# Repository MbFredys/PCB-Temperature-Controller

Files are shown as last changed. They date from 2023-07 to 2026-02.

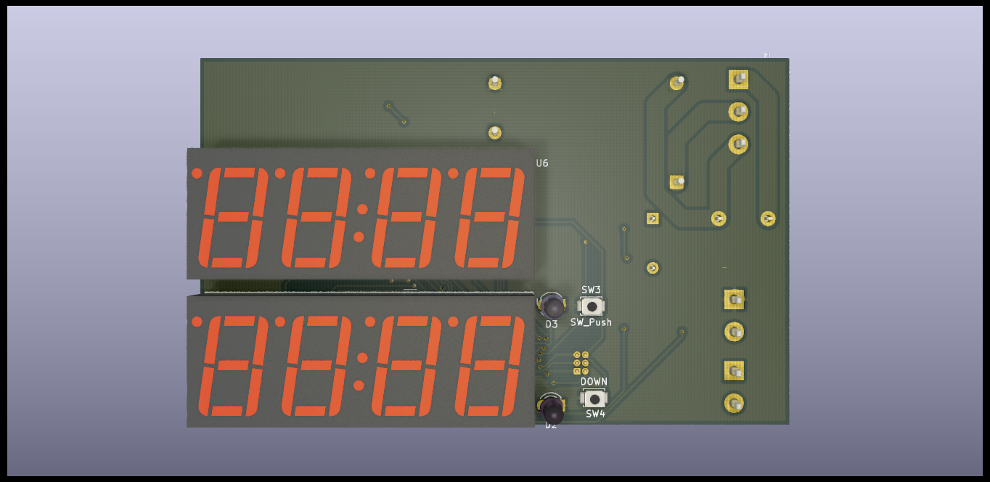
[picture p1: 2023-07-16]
Release/Controlador-temperatura-4.png

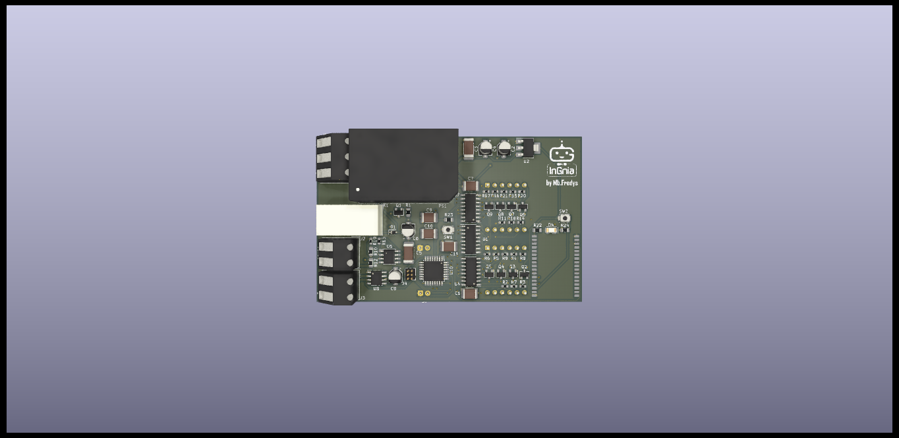
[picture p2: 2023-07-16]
Release/Controlador-temperatura-1.png

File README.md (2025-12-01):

<h1>Temperature Controller</h1>


This is a temperature controller PCB design that allows for precise temperature control with the following features:

1. 🌡️ Displays the current temperature value.
2. 🎯 Displays the desired temperature value.
3. ⬆️⬇️ Two buttons to raise and lower the temperature.
4. 🔌 Accepts a supply voltage of 100-240V AC.
5. 📶 Bluetooth communication.
6. 🌡️ Allows for the use of thermocouple and PT100 type sensors.

<h1>Usage</h1>

To use the temperature controller, follow these steps:

1. Connect the temperature controller to a power source using a 100-240V AC power supply.
2. Connect the desired temperature sensor to the temperature controller.
3. Set the desired temperature using the up and down buttons.
4. Monitor the current temperature on the display.

<h1>Getting Started</h1>

To get started with the temperature controller PCB design, follow these steps:

1. Clone this repository to your local machine.
2. Open the PCB design files in your preferred KiCAD software.
3. Review the design and make any necessary modifications.
4. Export the design files to your preferred format.
5. Send the design files to a PCB manufacturer for production.

<h1>Contributing</h1>

If you would like to contribute to the LED controller PCB design, please follow these steps:

1. Fork this repository.
2. Create a new branch.
3. Make your changes and commit them.
4. Submit a pull request.

<h1>License</h1>
This project is licensed under the CERN Open Hardware Licence Version 2 - Weakly Reciprocal (CERN-OHL-W-2.0).
See the <a href="https://gitlab.com/ohwr/project/cernohl/-/wikis/uploads/82b567f43ce515395f7ddbfbad7a8806/cern_ohl_w_v2.txt" target="_blank">CERN-OHL-W-2.0 ↗</a> file for more information.</p>

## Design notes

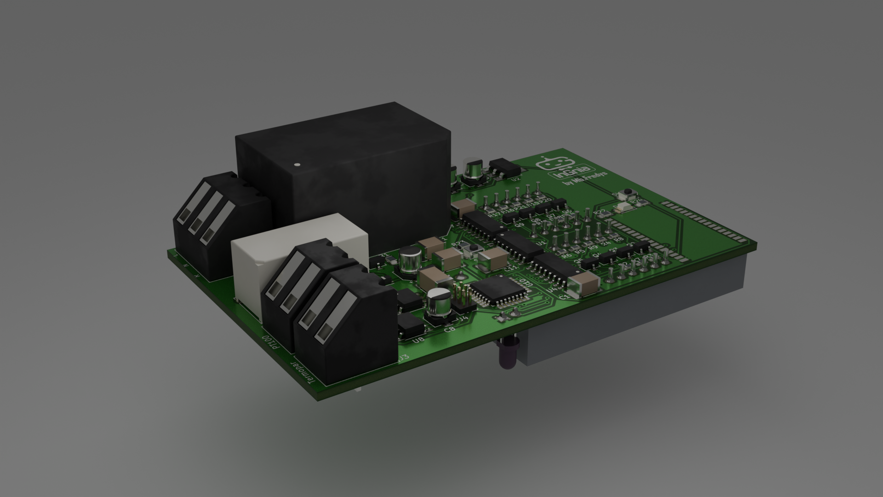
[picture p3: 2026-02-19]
Release/Controlador-temperatura-pro 1.png

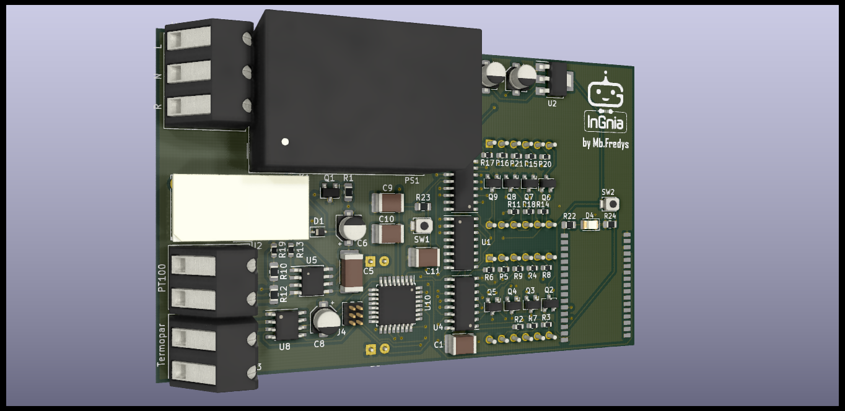
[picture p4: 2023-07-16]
Release/Controlador-temperatura-5.png

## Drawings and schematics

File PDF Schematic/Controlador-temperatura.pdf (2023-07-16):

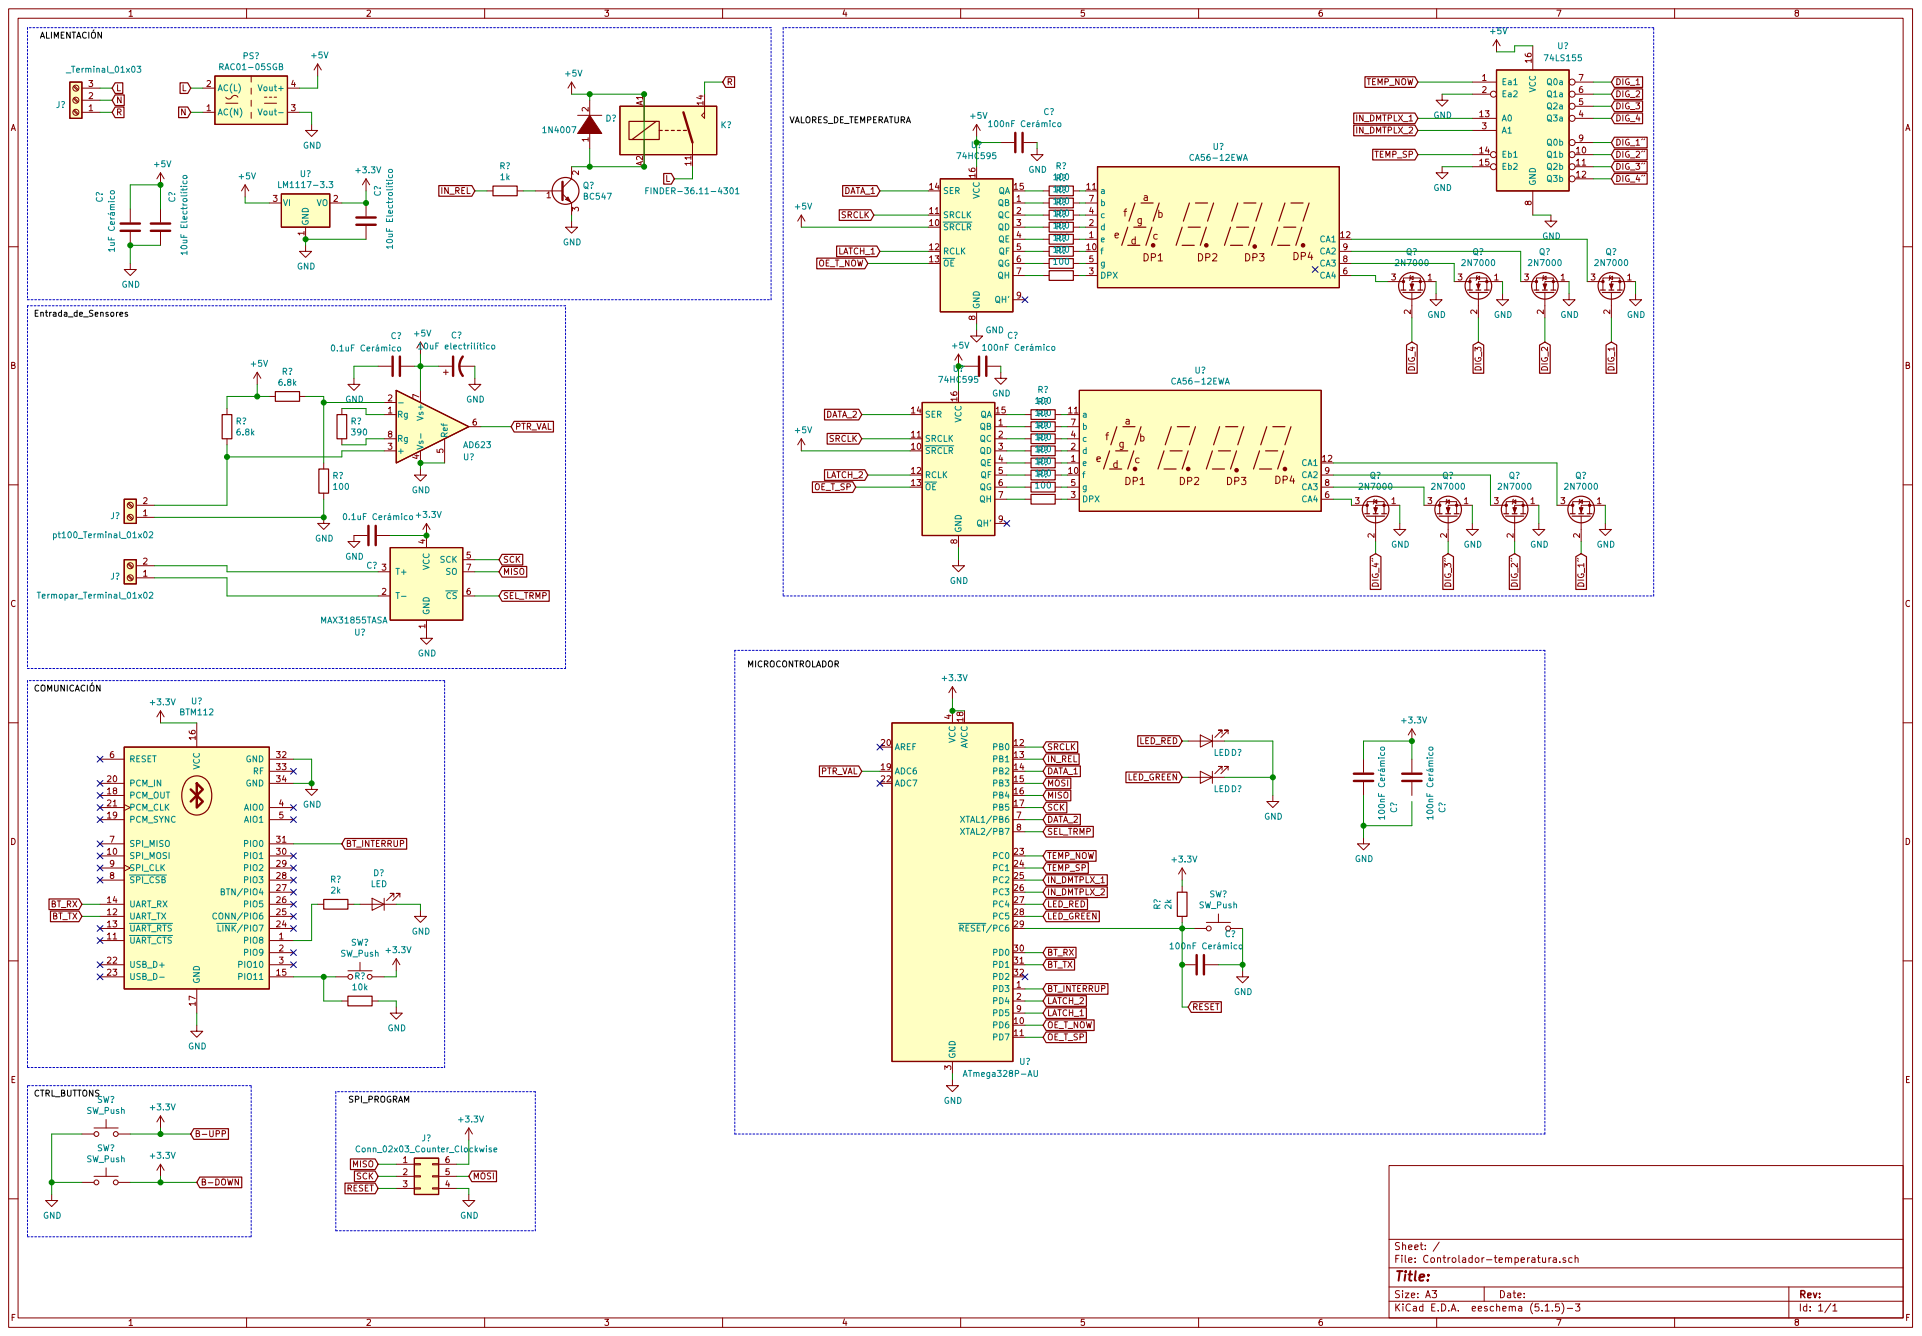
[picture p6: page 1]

SPI_PROGRAM +3.3V J? Conn_02x03_Counter_Clockwise

GND

File: Controlador-temperatura.sch Sheet: /

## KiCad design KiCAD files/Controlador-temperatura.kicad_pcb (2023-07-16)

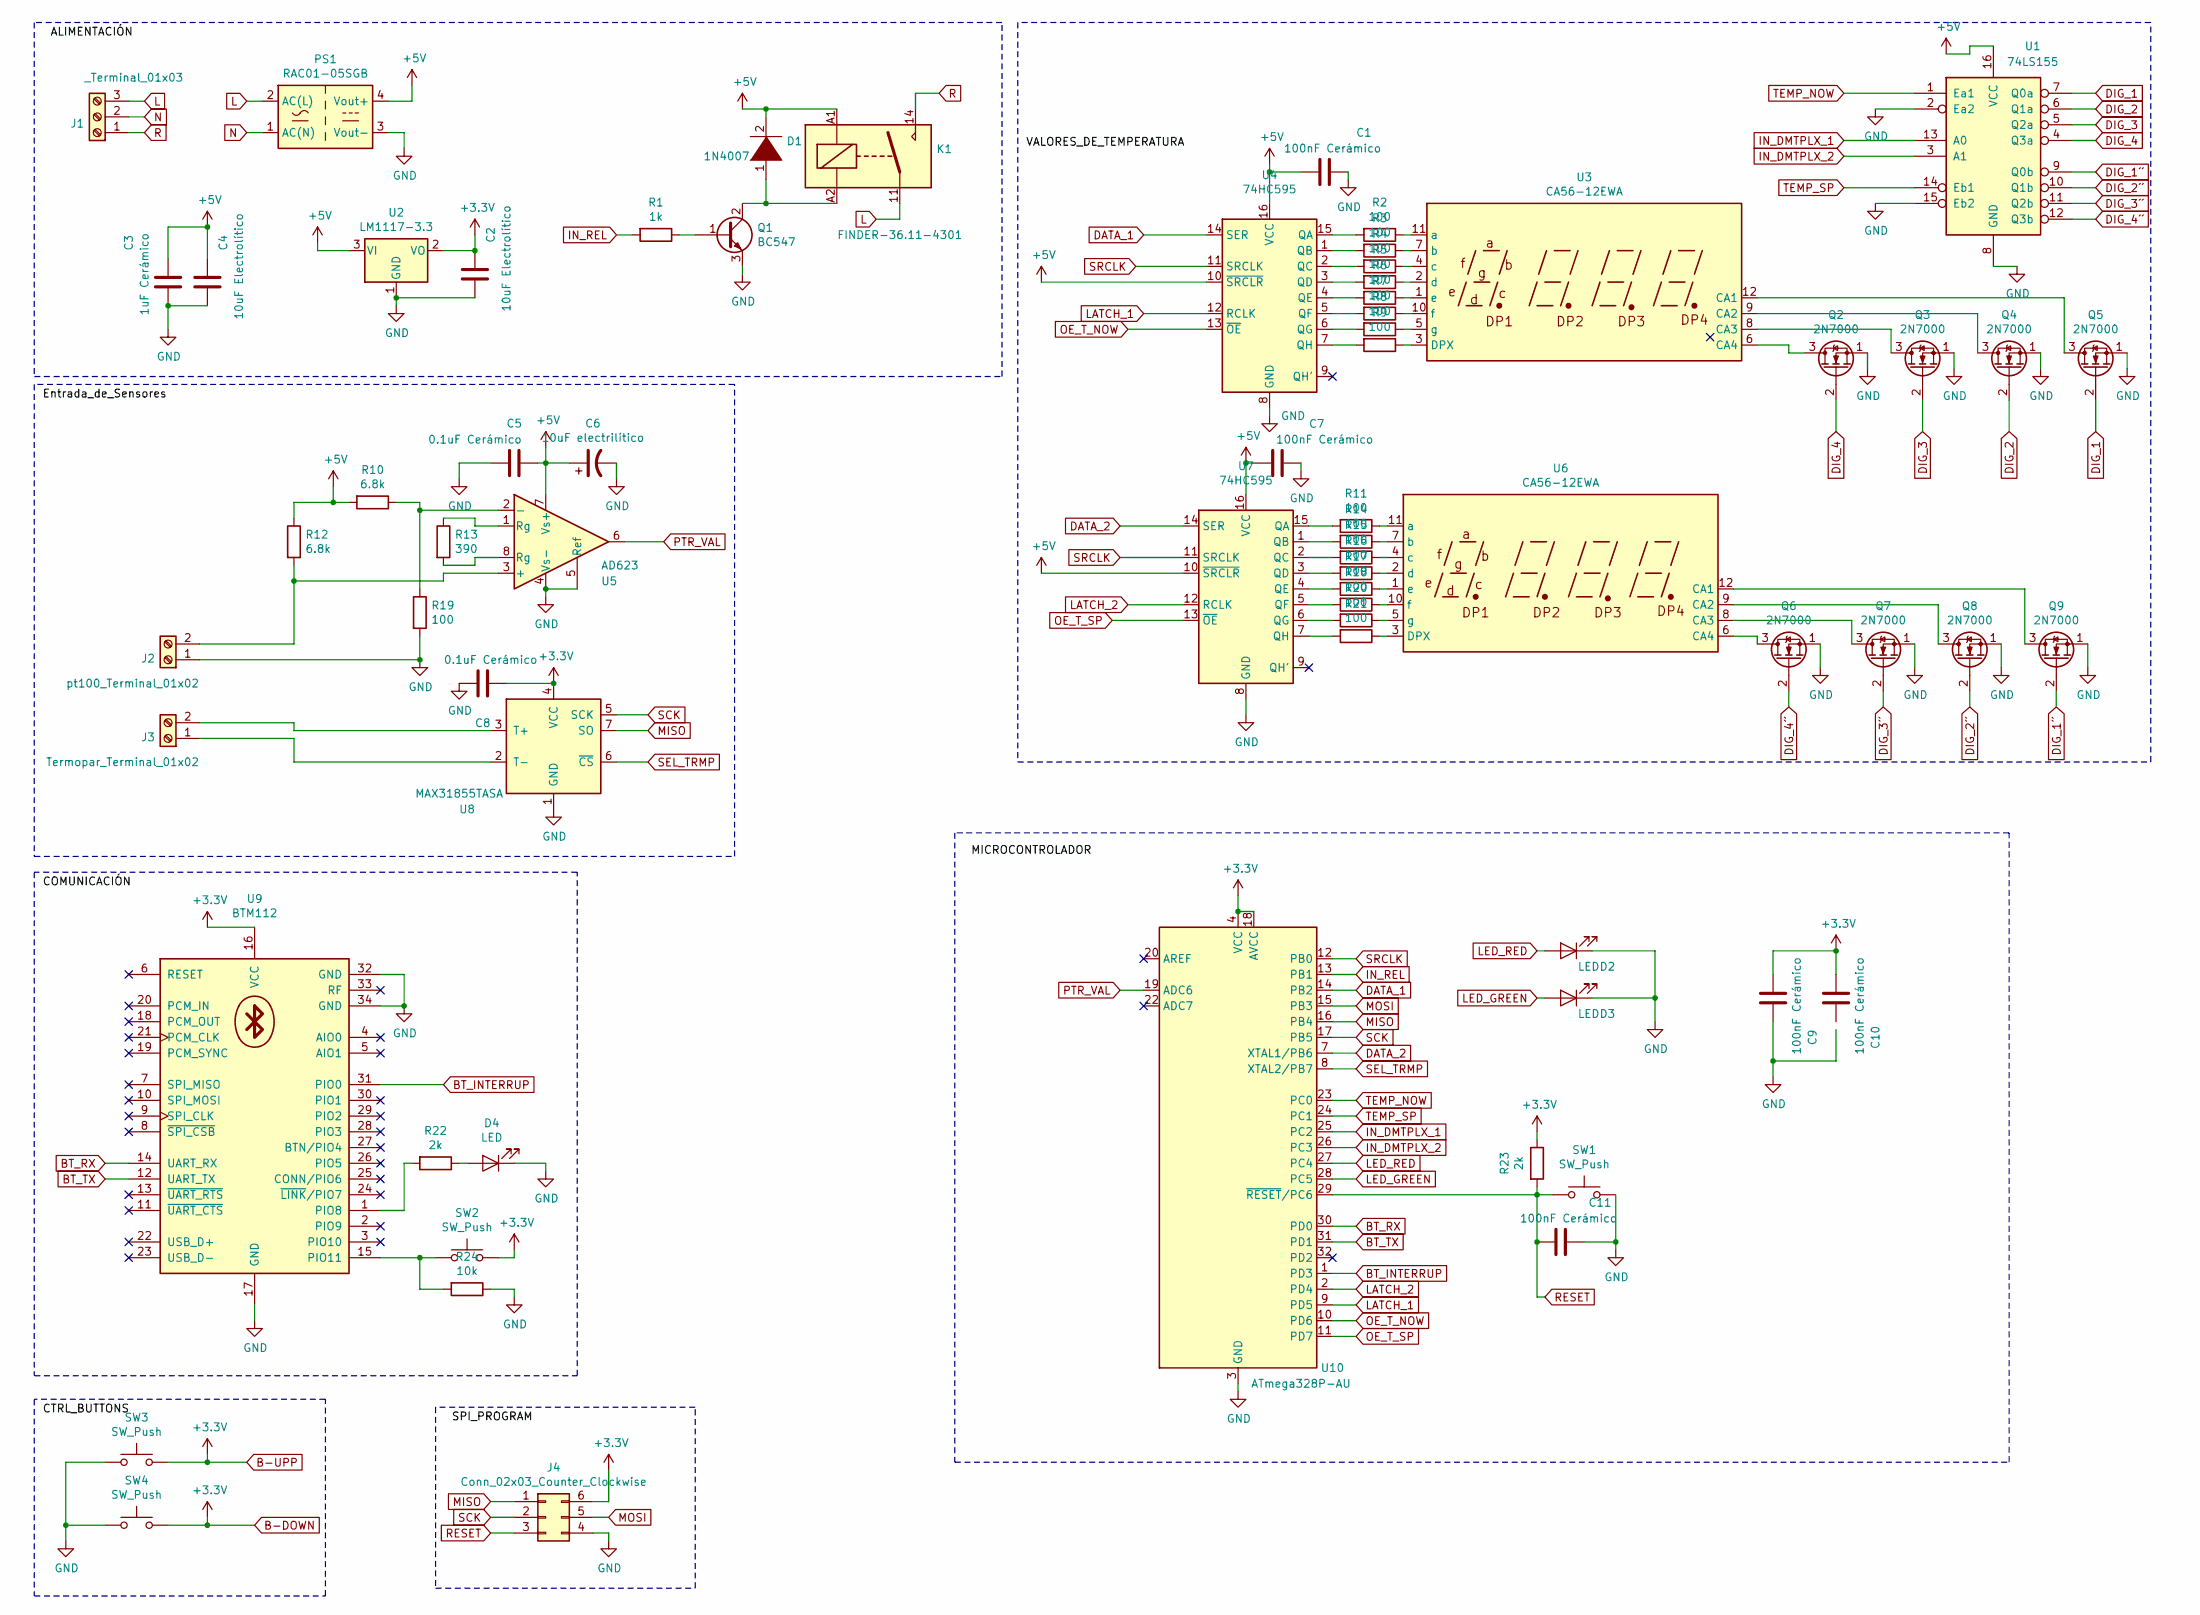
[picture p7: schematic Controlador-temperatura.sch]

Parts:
C1, C7, C9, C10, C11: 100nF Cerámico; C_1812_4532Metric_Pad1.30x3.40mm_HandSolder
C2, C4: 10uF Electrolítico; CP_Elec_4x4.5
C3: 1uF Cerámico; C_2512_6332Metric_Pad1.52x3.35mm_HandSolder
C5: 0.1uF Cerámico; C_2512_6332Metric_Pad1.52x3.35mm_HandSolder
C6: 10uF electrilítico; CP_Elec_4x4.5
C8: 0.1uF Cerámico; CP_Elec_4x4.5
D1: 1N4007; D_SOD-323
D2: LED; LED_D3.0mm_IRBlack
D3: LED; LED_D3.0mm_IRGrey
D4: LED; LED_1206_3216Metric
J1: _Terminal_01x03; TerminalBlock_Altech_AK300-3_P5.00mm
J2: pt100_Terminal_01x02; Altech_AK300_1x02_P5.00mm_45-Degree
J3: Termopar_Terminal_01x02; Altech_AK300_1x02_P5.00mm_45-Degree
J4: Conn_02x03_Counter_Clockwise; PinHeader_2x03_P1.27mm_Vertical
K1: FINDER-36.11-4301; Relay_SPST_Finder_32.21-x300
PS1: RAC01-05SGB; Converter_ACDC_RECOM_RAC01-xxSGB_THT
Q1: BC547; SC-59
Q2, Q3, Q4, Q5, Q6, Q7, Q8, Q9: 2N7000; SC-59
R1: 1k; R_0805_2012Metric_Pad1.15x1.40mm_HandSolder
R2, R3, R4, R5, R6, R7, R8, R9, R11, R14, R15, R16, R17, R18, R19, R20, R21: 100; R_0603_1608Metric
R10, R12: 6.8k; R_0805_2012Metric_Pad1.15x1.40mm_HandSolder
R13: 390; R_0603_1608Metric
R22, R23: 2k; R_0805_2012Metric_Pad1.15x1.40mm_HandSolder
R24: 10k; R_0805_2012Metric_Pad1.15x1.40mm_HandSolder
SW1, SW2, SW3, SW4: SW_Push; SW_SPST_B3U-1000P
U1: 74LS155; SOIC-16_3.9x9.9mm_P1.27mm
U2: LM1117-3.3; SOT-223-3_TabPin2
U3, U6: CA56-12EWA
U4, U7: 74HC595; SOIC-16_3.9x9.9mm_P1.27mm
U5: AD623; PowerIntegrations_SO-8
U8: MAX31855TASA; SOIC-8_3.9x4.9mm_P1.27mm
U9: BTM112; BTM-112
U10: ATmega328P-AU; TQFP-32_7x7mm_P0.8mm

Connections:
+5V: C1.1, C3.2, C4.2, C5.1, C6.1, C7.1, D1.2 (A), K1.A1, PS1.4 (Vout+), R10.2, R12.1, U1.16 (VCC), U2.3 (VI), U4.10 (~SRCLR), U4.16 (VCC), U5.7 (Vs+), U7.10 (~SRCLR), U7.16 (VCC)
B-DOWN: C2.2, C8.2, C9.1, C10.1, J4.6, R23.1, SW2.2, SW3.2, SW4.2, U2.2 (VO), U8.4 (VCC), U9.16 (VCC), U10.4 (VCC), U10.6 (VCC), U10.18 (AVCC)
BT_INTERRUP: U9.31 (PIO0), U10.1 (PD3)
BT_RX: U9.14 (UART_RX), U10.30 (PD0)
BT_TX: U9.12 (UART_TX), U10.31 (PD1)
DATA_1: U4.14 (SER), U10.14 (PB2)
DATA_2: U7.14 (SER), U10.7 (XTAL1/PB6)
DIG_1: Q5.2 (G), U1.7 (Q0a)
DIG_1´´: Q9.2 (G), U1.9 (Q0b)
DIG_2: Q4.2 (G), U1.6 (Q1a)
DIG_2´´: Q8.2 (G), U1.10 (Q1b)
DIG_3: Q3.2 (G), U1.5 (Q2a)
DIG_3´´: Q7.2 (G), U1.11 (Q2b)
DIG_4: Q2.2 (G), U1.4 (Q3a)
DIG_4´´: Q6.2 (G), U1.12 (Q3b)
GND: C1.2, C2.1, C3.1, C4.1, C5.2, C6.2, C7.2, C8.1, C9.2, C11.2, D2.1 (K), D3.1 (K), D4.1 (K), J2.1, J4.4, PS1.3 (Vout-), Q1.3 (E), Q2.1 (S), Q3.1 (S), Q4.1 (S), Q5.1 (S), Q6.1 (S), Q7.1 (S), Q8.1 (S), Q9.1 (S), R19.2, R24.1, SW1.2, SW3.1, SW4.1, U1.2 (Ea2), U1.8 (GND), U1.15 (Eb2), U2.1 (GND), U4.8 (GND), U5.4 (Vs-), U5.5 (Ref), U7.8 (GND), U8.1 (GND), U9.17 (GND), U9.32 (GND), U9.34 (GND), U10.3 (GND), U10.5 (GND), U10.21 (GND)
IN_DMTPLX_1: U1.13 (A0), U10.25 (PC2)
IN_DMTPLX_2: U1.3 (A1), U10.26 (PC3)
IN_REL: R1.2, U10.13 (PB1)
L: J1.3, K1.11, PS1.2 (AC(L))
LATCH_1: U4.12 (RCLK), U10.9 (PD5)
LATCH_2: U7.12 (RCLK), U10.2 (PD4)
LED_GREEN: D3.2 (A), U10.28 (PC5)
LED_RED: D2.2 (A), U10.27 (PC4)
MISO: J4.1, U8.7 (SO), U10.16 (PB4)
MOSI: J4.5, U10.15 (PB3)
N: J1.2, PS1.1 (AC(N))
unnamed: D1.1 (K), K1.A2, Q1.2 (C)
unnamed: D4.2 (A), R22.1
unnamed: J2.2, R12.2, U5.3 (+)
unnamed: J3.1, U8.2 (T-)
unnamed: J3.2, U8.3 (T+)
unnamed: Q1.1 (B), R1.1
unnamed: Q2.3 (D), U3.6 (CA4)
unnamed: Q3.3 (D), U3.8 (CA3)
unnamed: Q4.3 (D), U3.9 (CA2)
unnamed: Q5.3 (D), U3.12 (CA1)
unnamed: Q6.3 (D), U6.6 (CA4)
unnamed: Q7.3 (D), U6.8 (CA3)
unnamed: Q8.3 (D), U6.9 (CA2)
unnamed: Q9.3 (D), U6.12 (CA1)
unnamed: R2.1, U3.11 (a)
unnamed: R2.2, U4.15 (QA)
unnamed: R3.1, U3.7 (b)
unnamed: R3.2, U4.1 (QB)
unnamed: R4.1, U3.4 (c)
unnamed: R4.2, U4.2 (QC)
unnamed: R5.1, U3.2 (d)
unnamed: R5.2, U4.3 (QD)
unnamed: R6.1, U3.1 (e)
unnamed: R6.2, U4.4 (QE)
unnamed: R7.1, U3.10 (f)
unnamed: R7.2, U4.5 (QF)
unnamed: R8.1, U3.5 (g)
unnamed: R8.2, U4.6 (QG)
unnamed: R9.1, U3.3 (DPX)
unnamed: R9.2, U4.7 (QH)
unnamed: R10.1, R19.1, U5.2 (-)
unnamed: R11.1, U6.11 (a)
unnamed: R11.2, U7.15 (QA)
unnamed: R13.1, U5.1 (Rg)
unnamed: R13.2, U5.8 (Rg)
unnamed: R14.1, U6.7 (b)
unnamed: R14.2, U7.1 (QB)
unnamed: R15.1, U6.4 (c)
unnamed: R15.2, U7.2 (QC)
unnamed: R16.1, U6.2 (d)
unnamed: R16.2, U7.3 (QD)
unnamed: R17.1, U6.1 (e)
unnamed: R17.2, U7.4 (QE)
unnamed: R18.1, U6.10 (f)
unnamed: R18.2, U7.5 (QF)
unnamed: R20.1, U6.5 (g)
unnamed: R20.2, U7.6 (QG)
unnamed: R21.1, U6.3 (DPX)
unnamed: R21.2, U7.7 (QH)
unnamed: R22.2, U9.1 (PIO8)
unnamed: R24.2, SW2.1, U9.15 (PIO11)
OE_T_NOW: U4.13 (~OE), U10.10 (PD6)
OE_T_SP: U7.13 (~OE), U10.11 (PD7)
PTR_VAL: U5.6, U10.19 (ADC6)
R: J1.1, K1.14
RESET: C11.1, J4.3, R23.2, SW1.1, U10.29 (~RESET~/PC6)
SCK: J4.2, U8.5 (SCK), U10.17 (PB5)
SEL_TRMP: U8.6 (~CS~), U10.8 (XTAL2/PB7)
SRCLK: U4.11 (SRCLK), U7.11 (SRCLK), U10.12 (PB0)
TEMP_NOW: U1.1 (Ea1), U10.23 (PC0)
TEMP_SP: U1.14 (Eb1), U10.24 (PC1)

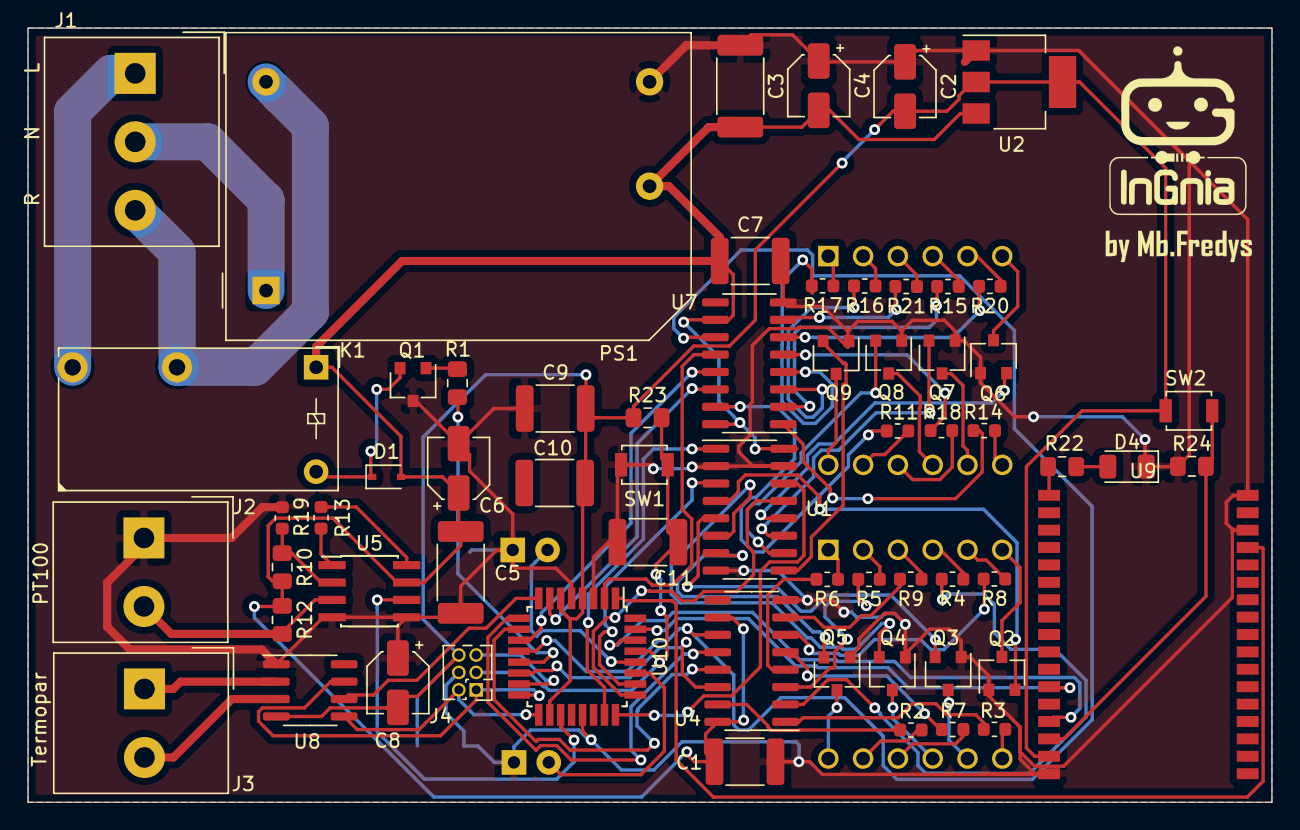
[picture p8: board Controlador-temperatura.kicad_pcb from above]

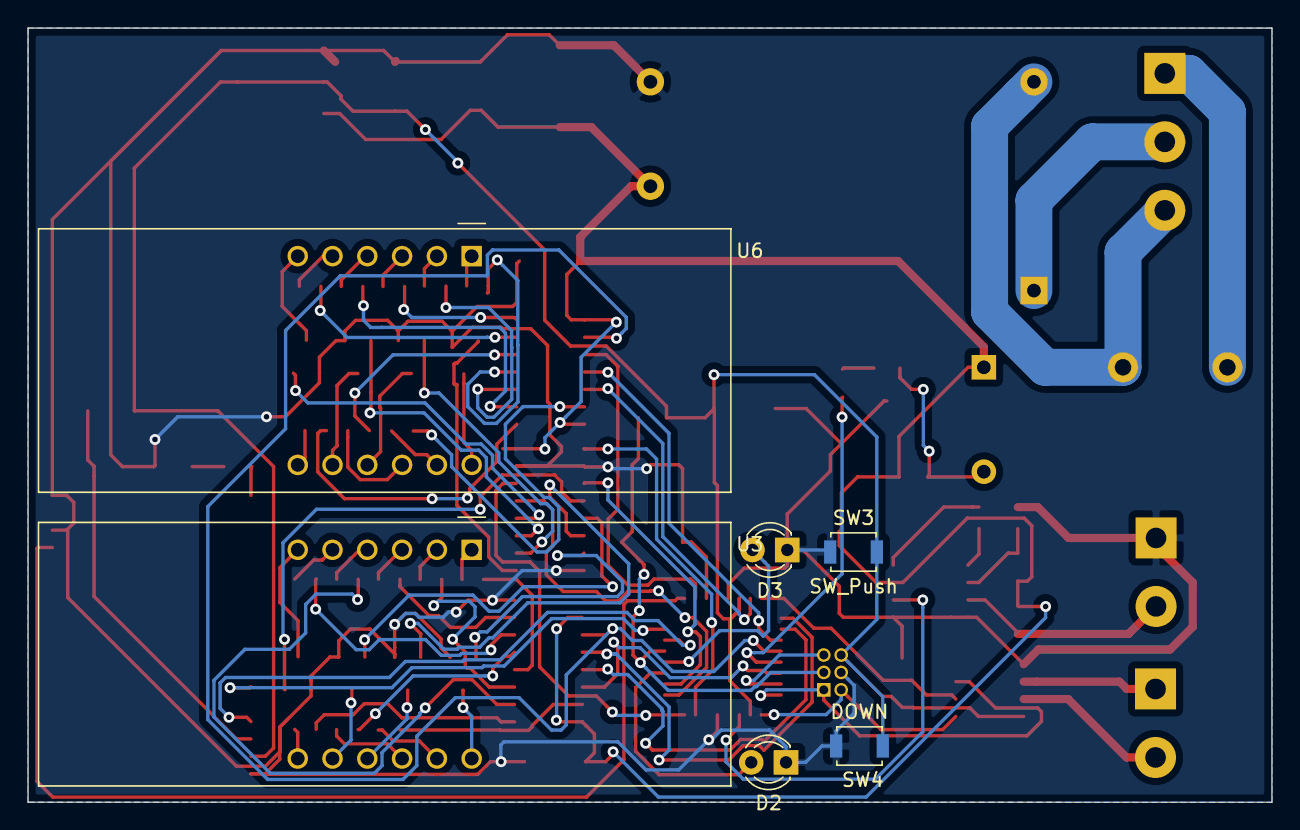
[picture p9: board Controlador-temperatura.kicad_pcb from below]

Board: 2 copper layers, 90.8 x 56.5 mm, 68 parts (6 on the bottom side), 88 nets.

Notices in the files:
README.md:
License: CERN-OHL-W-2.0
